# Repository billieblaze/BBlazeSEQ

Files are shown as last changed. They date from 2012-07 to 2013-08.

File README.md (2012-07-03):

BBlaze-SEQ
==========

Arduino Based Midi Sequencer w/ LCD, Nav Buttons, RGB LED Matrix / Keypad

This is my first Arduino Project, but not my first microcontroller project.   

Platform: 
=========

* SainSmart Arduino Mega 2560 clone
* SainSmart i2c LCD
* MIDI IN / MIDI OUT (6n139)
* MicroChip 24LC256 - 256k RAM 
* SparkFun 4x4 RGB LED / Button Matrix - 74hc595 shift registers for LED - 74hc164/165 for button matrix

* Navigation 
    - using a digital in module from Midibox.org - but again, just some 74hc595
    * 8 rotary encoder / swithces 
    * 5 nav buttons
    * pattern change rotary/encoder

Libraries:
==========

* SainSmart i2c LCD
* ShiftMatrixPWM
* MIDI 
* Timer3 

Roadmap: 
========

* add save / clear / copy pattern
* allow CC data in the pattern
* PCB Design

ChangeLog:
==========

* v0.9 - Split core .ino file into packages (lcd, keypad, matrix, etc) - working on timing (might remove interrupt) and general cleanup of UI handlers
* v0.8 - Added 24LC256 - working on timing of UI routines - added "record+keyboard" mode
* v0.7 - moved the button handling to an interrupt and added "updateLCD" flag which will update on the next loop()
* v0.6 - switch to i2c LCD and arduino mega 2560
* v0.5 - Replace sequence array that come from Cahors / buttons now toggle notes in the array
* v0.4 - Integrate Keypad w/ a Voltage Divider to A5
* v0.3 - Integrate LED Matrix (shiftPWMMatrix + 75hc595)
* v0.2 - LCD / Menu / Nav Buttons / Simple OS   (sainSmart LCD / Keypad)
* v0.1 - basic poc / find libraries

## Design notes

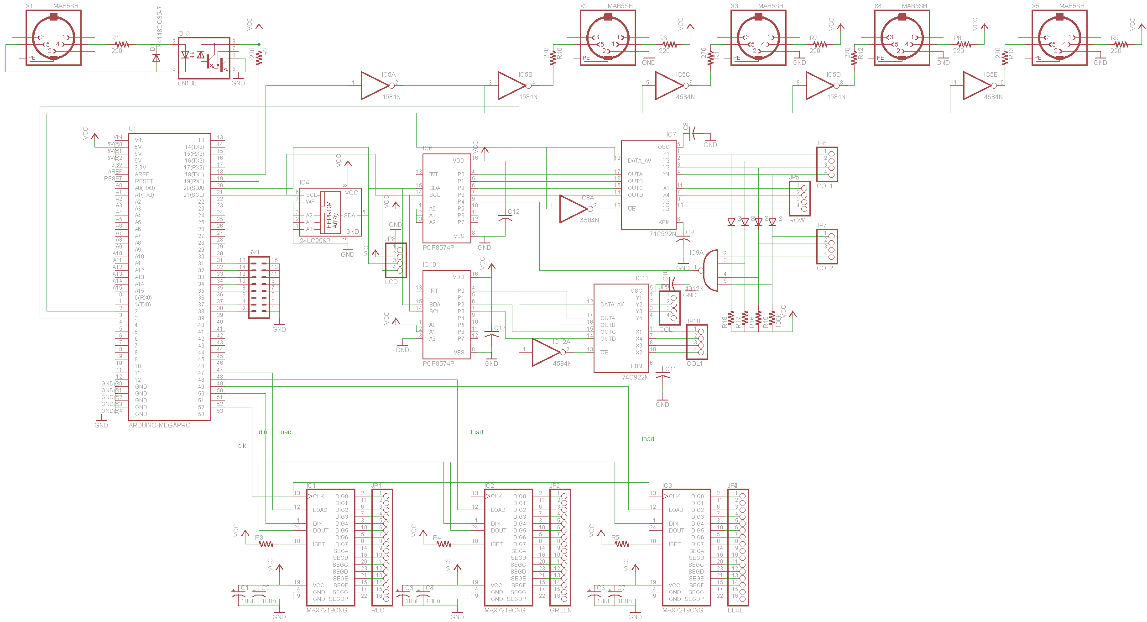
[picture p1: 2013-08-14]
bblazeSeq/schematic.png

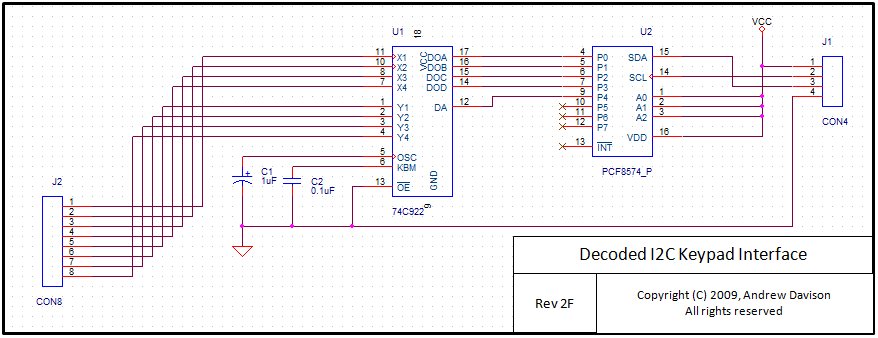
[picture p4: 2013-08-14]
bblazeSeq/74C922_circuit.png

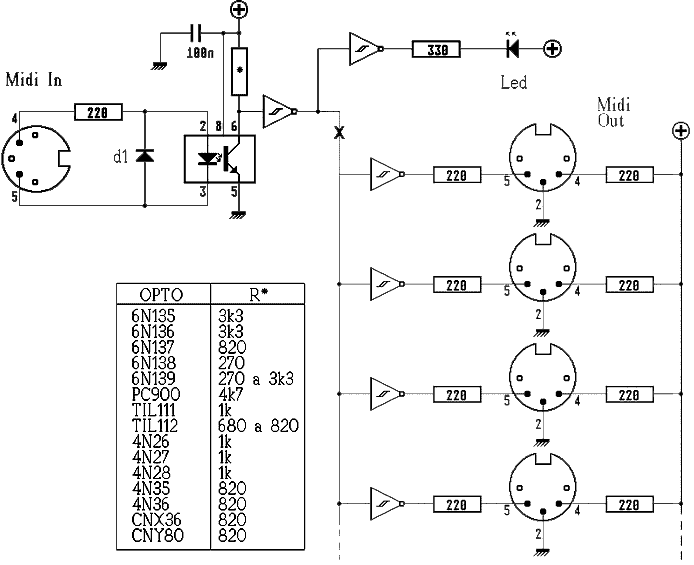
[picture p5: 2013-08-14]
bblazeSeq/midithrubox.gif

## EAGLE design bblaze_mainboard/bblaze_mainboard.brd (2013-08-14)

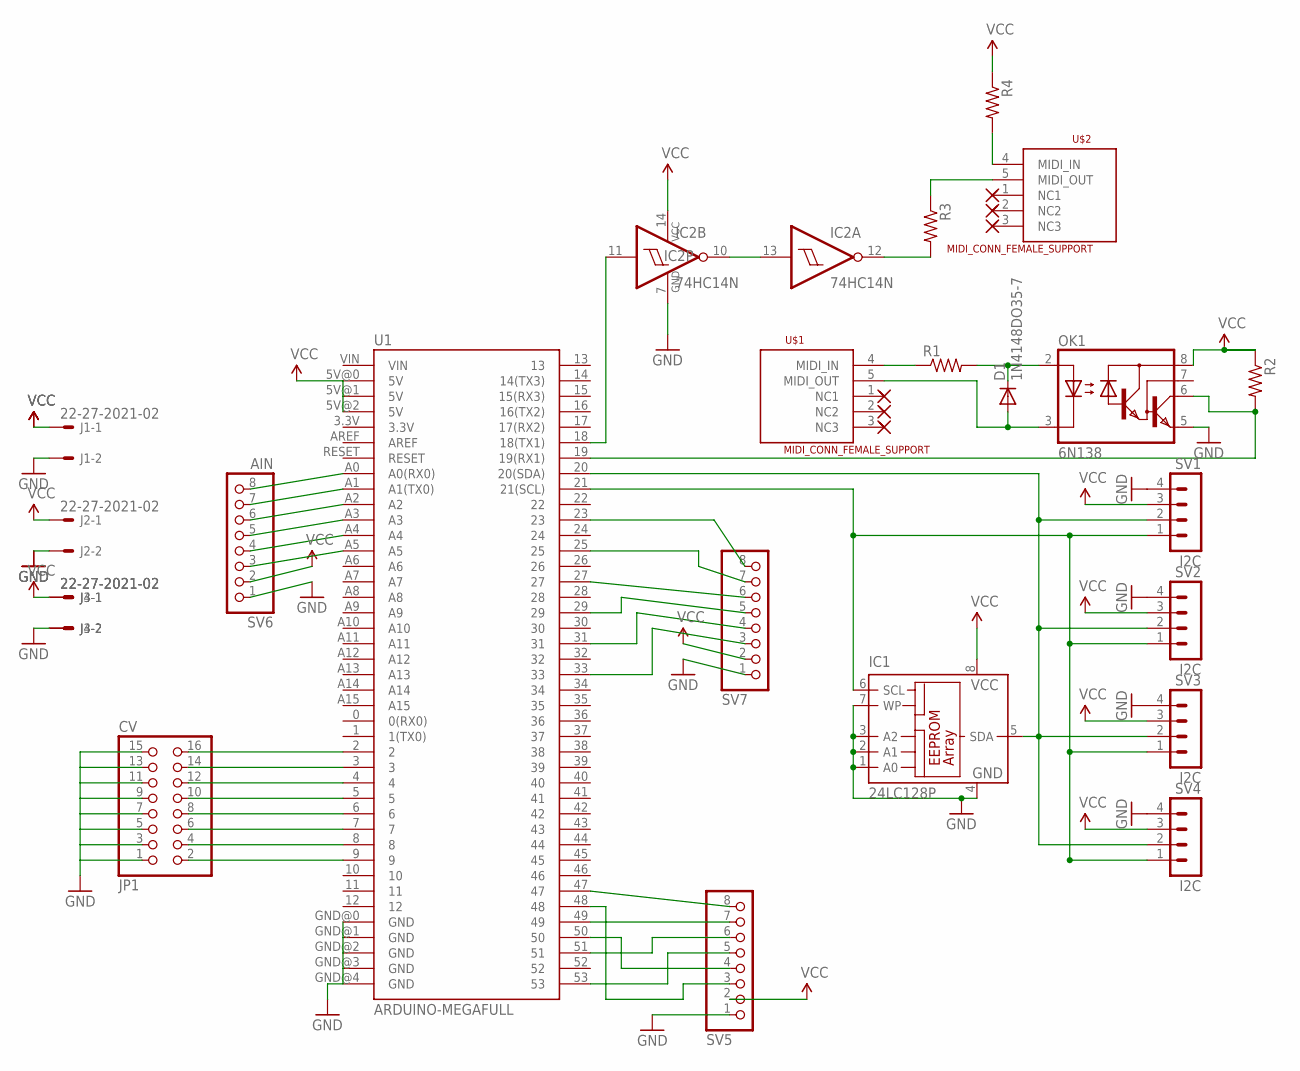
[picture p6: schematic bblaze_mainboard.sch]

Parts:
D1: 1N4148DO35-7; DO35-7
IC1: 24LC128P; DIL8
IC2: 74HC14N; DIL14
J1, J2, J3, J4: 22-27-2021-02; 6410-02
JP1: CV; 2X08
OK1: 6N138; DIL08
R1, R2, R3, R4: RESISTORKIT; AXIAL-0.3-KIT
SV1, SV2, SV3, SV4: I2C; MA04-1
SV5, SV7: PINHD-1X8; 1X08
SV6: AIN; 1X08
U1: ARDUINO-MEGAFULL; ARDUINO_MEGA
U$1, U$2: MIDI_CONN_FEMALE_SUPPORT; DIN_5_FEMALE_SUPPORT

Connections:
GND: IC1.1 (A0), IC1.2 (A1), IC1.3 (A2), IC1.4 (GND), IC1.7 (WP), IC2.7 (GND), J1.2, J2.2, J3.2, J4.2, JP1.1, JP1.3, JP1.5, JP1.7, JP1.9, JP1.11, JP1.13, JP1.15, OK1.5 (GND), SV1.4, SV2.4, SV3.4, SV4.4, SV5.1, SV6.1, SV7.1, U1.GND@0 (GND), U1.GND@1 (GND), U1.GND@2 (GND), U1.GND@3 (GND), U1.GND@4 (GND)
unnamed: D1.C, OK1.2 (A), R1.P$2 (2)
unnamed: D1.A, OK1.3 (C), U$1.5 (MIDI_OUT)
unnamed: R1.P$1 (1), U$1.4 (MIDI_IN)
unnamed: JP1.16, U1.2
unnamed: OK1.8 (VCC), R2.P$1 (1)
unnamed: OK1.6 (VO), R2.P$2 (2), U1.19 (19(RX1))
unnamed: JP1.14, U1.3
unnamed: IC1.5 (SDA), SV1.2, SV2.2, SV3.2, SV4.2, U1.20 (20(SDA))
unnamed: IC1.6 (SCL), SV1.1, SV2.1, SV3.1, SV4.1, U1.21 (21(SCL))
unnamed: JP1.12, U1.4
unnamed: JP1.10, U1.5
unnamed: JP1.8, U1.6
unnamed: JP1.6, U1.7
unnamed: JP1.4, U1.8
unnamed: JP1.2, U1.9
unnamed: SV5.5, U1.53
unnamed: SV5.6, U1.51
unnamed: SV5.4, U1.50
unnamed: SV5.3, U1.48
unnamed: SV5.8, U1.47
unnamed: IC2.11 (I), U1.18 (18(TX1))
unnamed: IC2.10 (O), IC2.13 (I)
unnamed: IC2.12 (O), R3.P$2 (2)
unnamed: R3.P$1 (1), U$2.5 (MIDI_OUT)
unnamed: R4.P$2 (2), U$2.4 (MIDI_IN)
unnamed: SV6.8, U1.A0 (A0(RX0))
unnamed: SV6.7, U1.A1 (A1(TX0))
unnamed: SV6.6, U1.A2
unnamed: SV6.5, U1.A3
unnamed: SV6.4, U1.A4
unnamed: SV6.3, U1.A5
unnamed: SV7.8, U1.23
unnamed: SV7.7, U1.25
unnamed: SV7.6, U1.27
unnamed: SV7.5, U1.29
unnamed: SV7.4, U1.31
unnamed: SV7.3, U1.33
unnamed: SV5.7, U1.49
VCC: IC1.8 (VCC), IC2.14 (VCC), J1.1, J2.1, J3.1, J4.1, R4.P$1 (1), SV1.3, SV2.3, SV3.3, SV4.3, SV5.2, SV6.2, SV7.2, U1.5V@0 (5V), U1.5V@1 (5V), U1.5V@2 (5V)

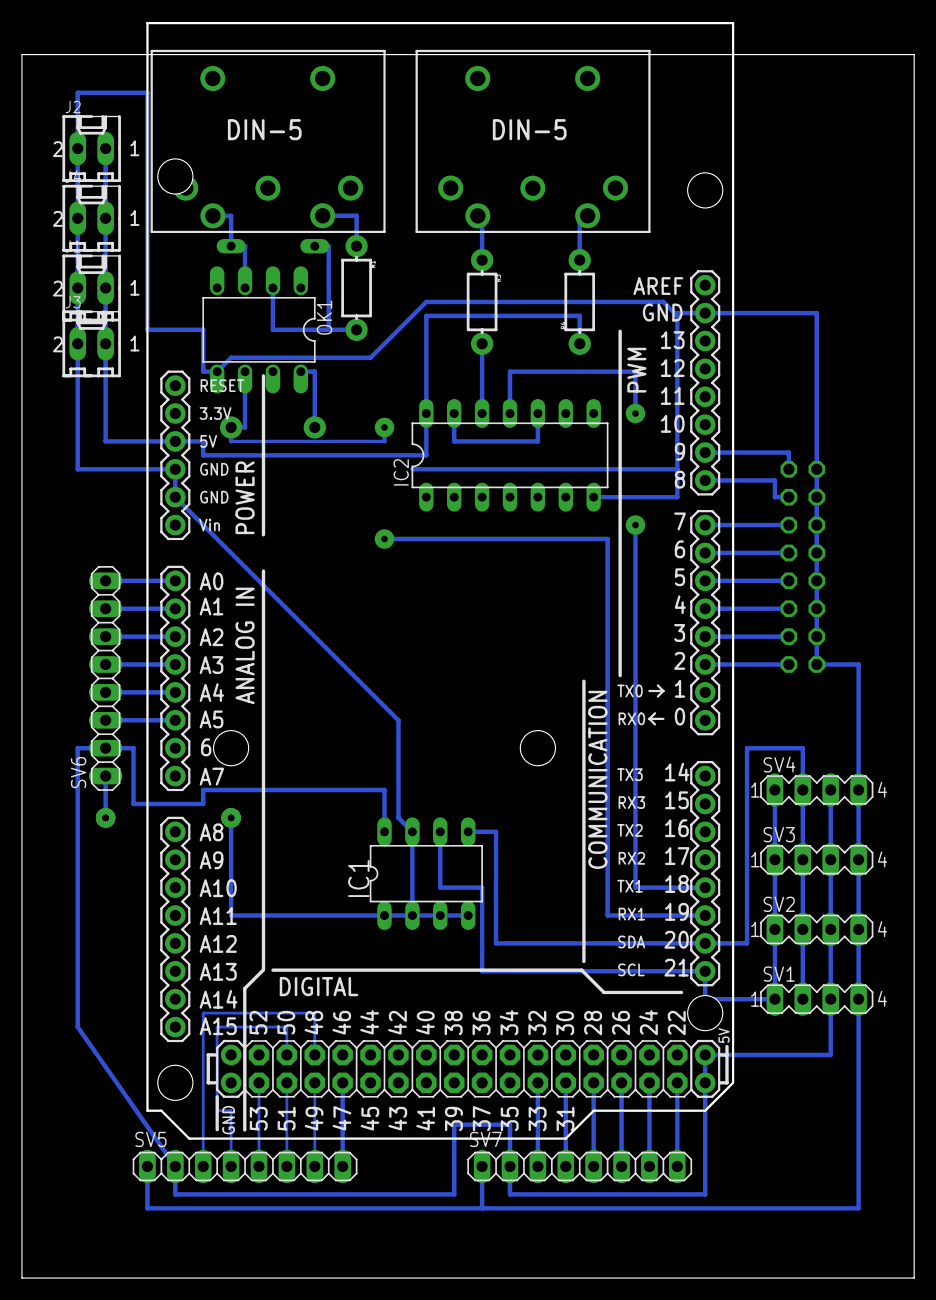
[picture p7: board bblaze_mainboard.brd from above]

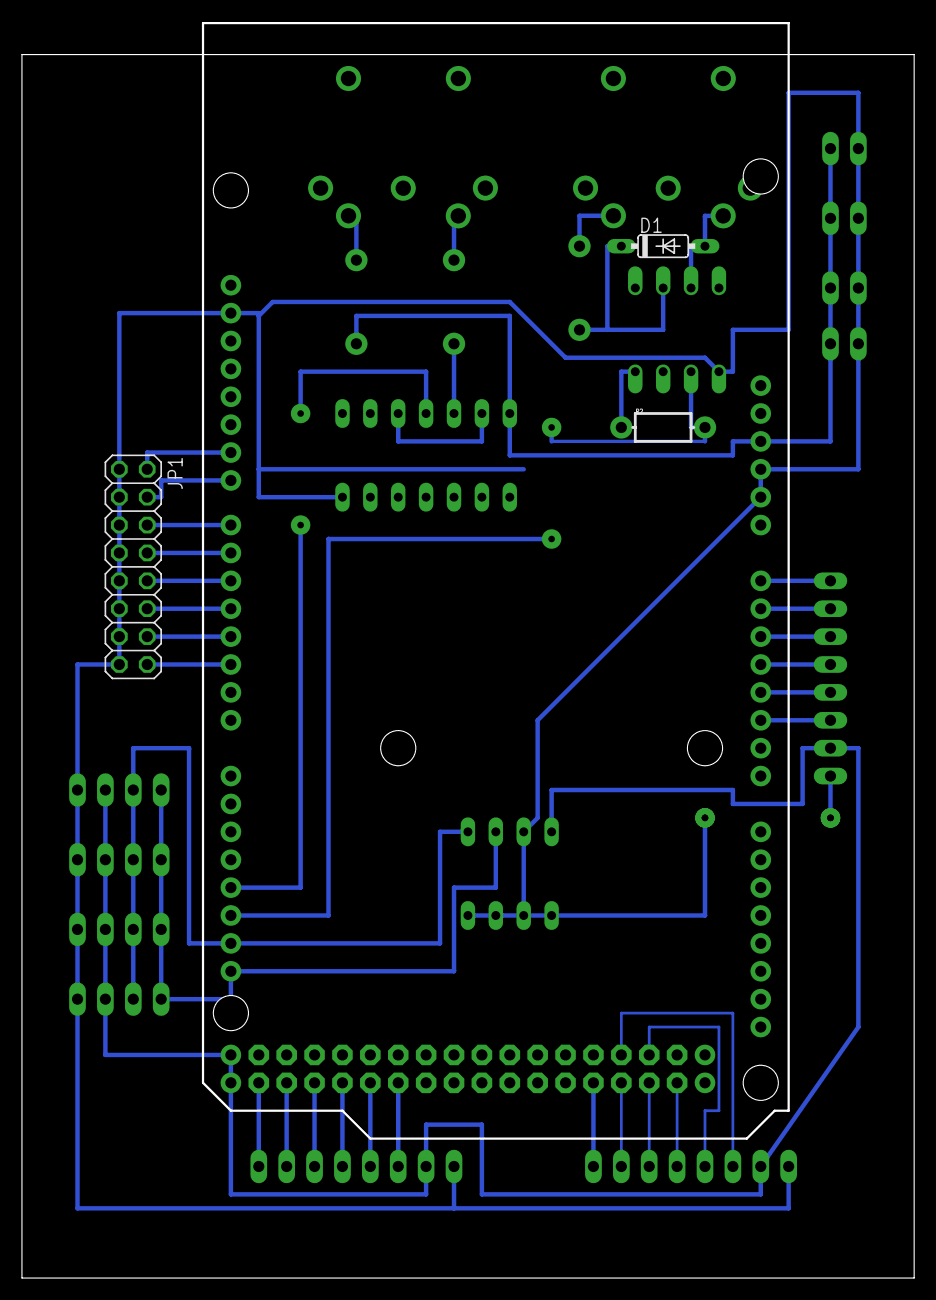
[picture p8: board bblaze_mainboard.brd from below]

Board: 2 copper layers, 81.3 x 114.3 mm, 23 parts (3 on the bottom side), 40 nets.

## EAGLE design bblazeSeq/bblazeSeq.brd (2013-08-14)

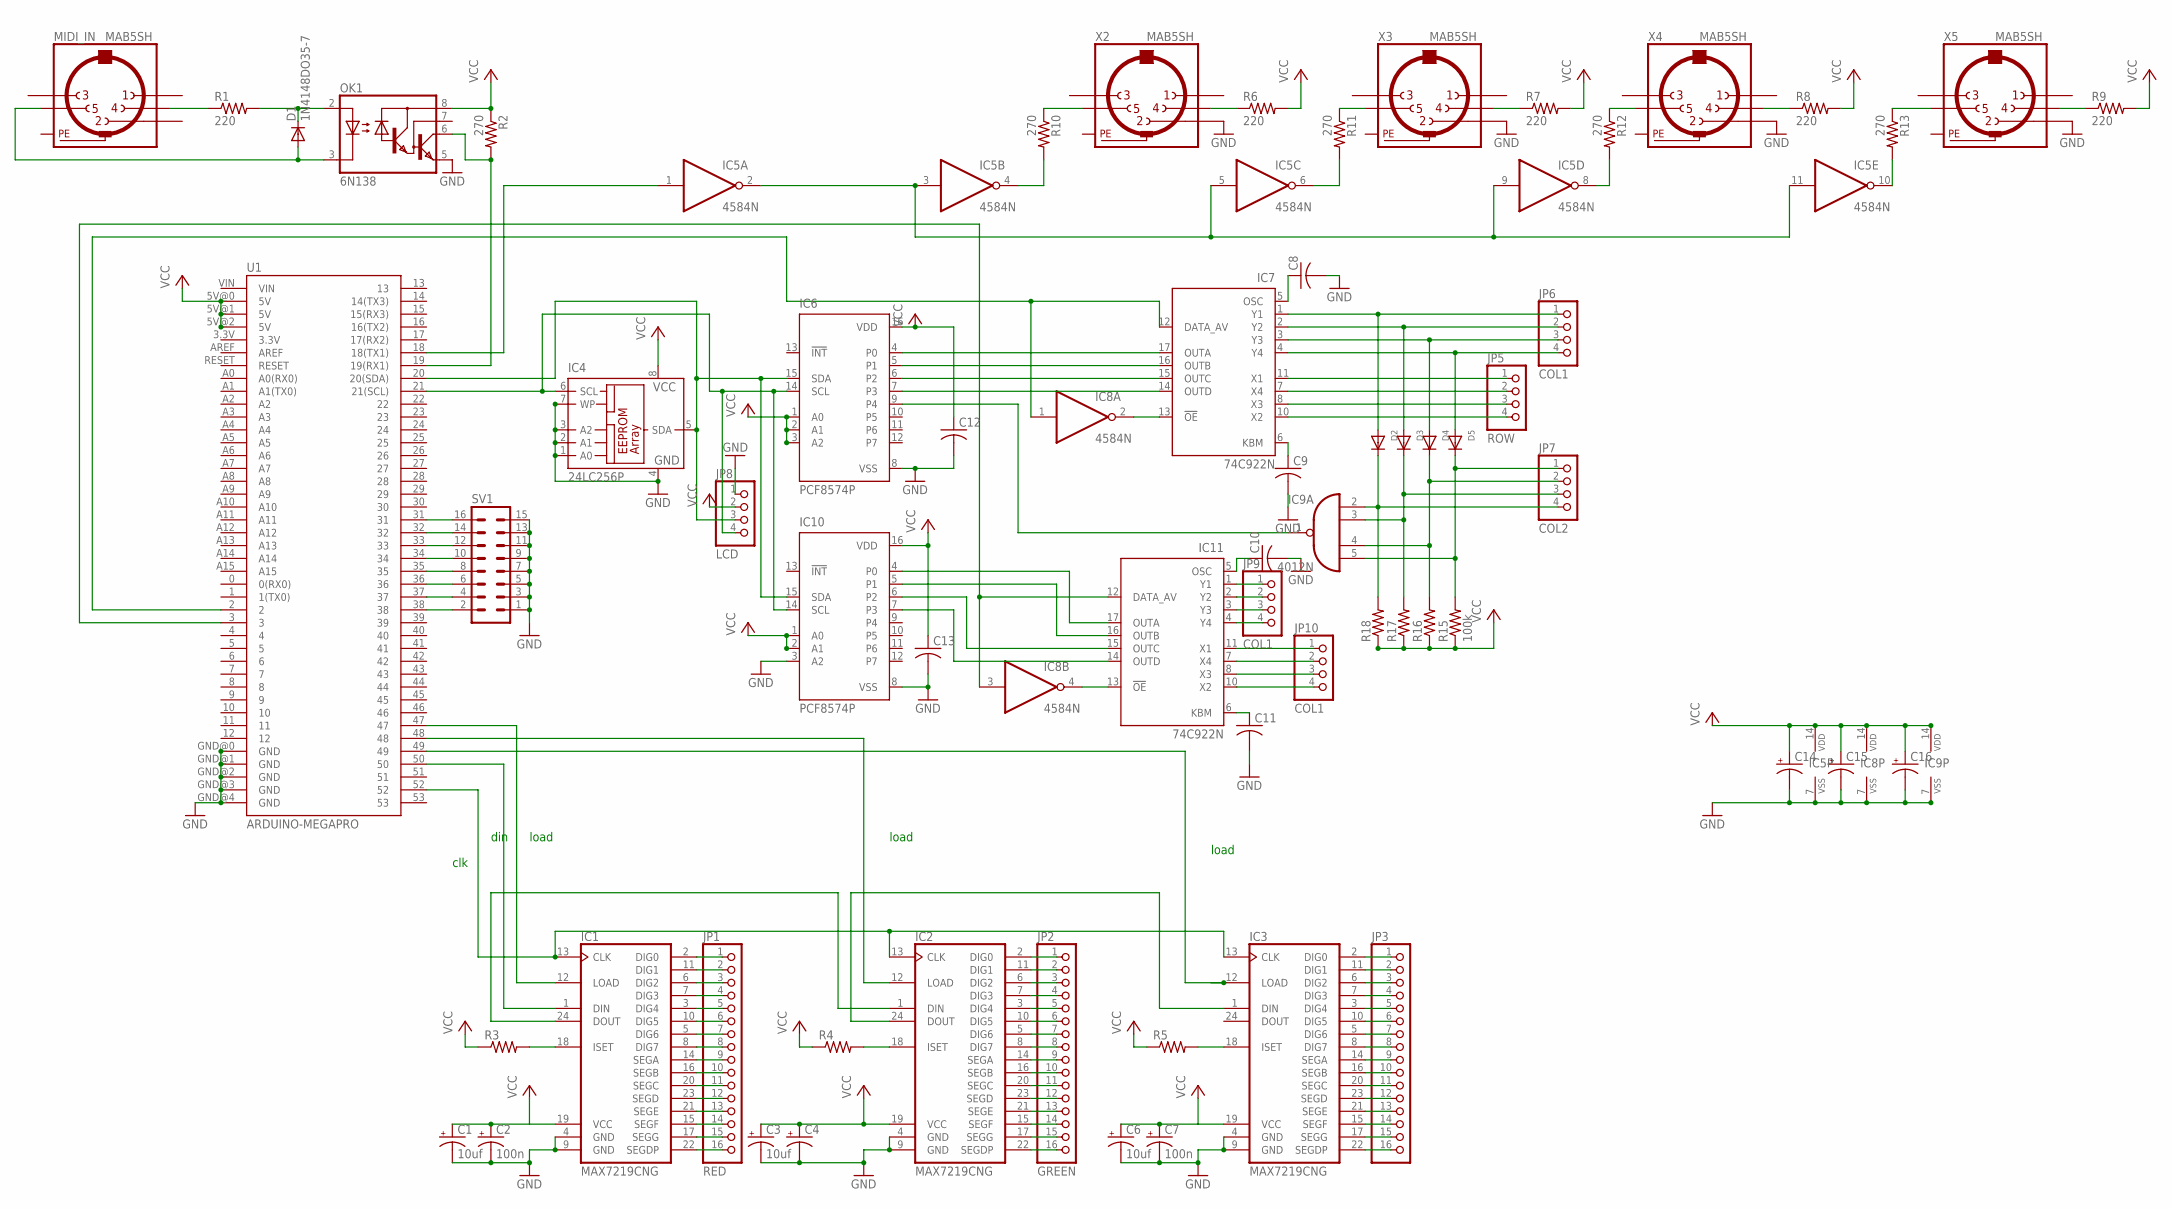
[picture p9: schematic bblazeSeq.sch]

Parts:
C1, C3, C6: 10uf; E2,5-6E
C2, C7: 100n; E2,5-6E
C4, C14, C15, C16: CPOL-USE2,5-6E; E2,5-6E
C8, C9, C10, C11, C12, C13: C-US050-024X044; C050-024X044
D1: 1N4148DO35-7; DO35-7
D2, D3, D4, D5: DIODEDO-1N4148; DO-1N4148
IC1, IC2, IC3: MAX7219CNG; DIL24-3
IC4: 24LC256P; DIL8
IC5, IC8: 4584N; DIL14
IC6, IC10: PCF8574P; DIL16
IC7, IC11: 74C922N; DIL18
IC9: 4012N; DIL14
JP1: RED; 1X16
JP2: GREEN; 1X16
JP3: PINHD-1X16; 1X16
JP5: ROW; 1X04
JP6, JP9, JP10: COL1; 1X04
JP7: COL2; 1X04
JP8: LCD; 1X04
MIDI_IN: MAB5SH
OK1: 6N138; DIL08
R1: 220; 0207/10
R2, R10, R11, R12, R13: 270; 0207/10
R3, R4, R5, R16, R17, R18: R-US_0204/7; 0204/7
R6, R7, R8, R9: 220; 0204/7
R15: 100k; 0204/7
SV1: MA08-2
U1: ARDUINO-MEGAPRO; ARDUINO_MEGA-PRO-3.3V
X2, X3, X4, X5: MAB5SH

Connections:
GND: C1.-, C2.-, C3.-, C4.-, C6.-, C7.-, C8.2, C9.2, C10.2, C11.2, C12.2, C13.2, C14.-, C15.-, C16.-, IC1.4 (GND), IC1.9 (GND), IC2.4 (GND), IC2.9 (GND), IC3.4 (GND), IC3.9 (GND), IC4.1 (A0), IC4.2 (A1), IC4.3 (A2), IC4.4 (GND), IC4.7 (WP), IC5.7 (VSS), IC6.8 (VSS), IC7.9 (GND), IC8.7 (VSS), IC9.7 (VSS), IC10.3 (A2), IC10.8 (VSS), IC11.9 (GND), JP8.1, OK1.5 (GND), SV1.1, SV1.3, SV1.5, SV1.7, SV1.9, SV1.11, SV1.13, SV1.15, U1.GND@0 (GND), U1.GND@1 (GND), U1.GND@2 (GND), U1.GND@3 (GND), U1.GND@4 (GND), X2.2, X3.2, X4.2, X5.2
unnamed: IC6.9 (P4), IC9.1 (O)
unnamed: D2.C, IC9.2 (I0), JP7.4, R18.2
unnamed: D3.C, IC9.3 (I1), JP7.3, R17.2
unnamed: D4.C, IC9.4 (I2), JP7.2, R16.2
unnamed: D5.C, IC9.5 (I3), JP7.1, R15.2
unnamed: IC3.2 (DIG0), JP3.1
unnamed: IC3.11 (DIG1), JP3.2
unnamed: IC3.6 (DIG2), JP3.3
unnamed: IC3.7 (DIG3), JP3.4
unnamed: IC3.3 (DIG4), JP3.5
unnamed: IC3.10 (DIG5), JP3.6
unnamed: IC3.5 (DIG6), JP3.7
unnamed: IC3.8 (DIG7), JP3.8
unnamed: IC3.14 (SEGA), JP3.9
unnamed: D1.A, MIDI_IN.5, OK1.3 (C)
unnamed: D1.C, OK1.2 (A), R1.2
unnamed: MIDI_IN.4, R1.1
unnamed: OK1.6 (VO), R2.2, U1.19 (19(RX1))
unnamed: IC1.18 (ISET), R3.2
unnamed: IC4.6 (SCL), IC6.14 (SCL), IC10.14 (SCL), JP8.4, U1.21 (21(SCL))
unnamed: IC4.5 (SDA), IC6.15 (SDA), IC10.15 (SDA), JP8.3, U1.20 (20(SDA))
unnamed: IC2.18 (ISET), R4.2
unnamed: IC3.18 (ISET), R5.2
unnamed: IC3.12 (LOAD), U1.49
unnamed: IC2.12 (LOAD), U1.48
unnamed: C1.+, C2.+, IC1.19 (VCC)
unnamed: IC5.1 (I), U1.18 (18(TX1))
unnamed: C6.+, C7.+, IC3.19 (VCC)
unnamed: IC2.24 (DOUT), IC3.1 (DIN)
unnamed: IC1.24 (DOUT), IC2.1 (DIN)
unnamed: IC1.13 (CLK), IC2.13 (CLK), IC3.13 (CLK), U1.52
unnamed: R6.1, X2.4
unnamed: IC1.1 (DIN), U1.50
unnamed: IC1.12 (LOAD), U1.47
unnamed: R7.1, X3.4
unnamed: R8.1, X4.4
unnamed: R9.1, X5.4
unnamed: R10.1, X2.5
unnamed: R11.1, X3.5
unnamed: R12.1, X4.5
unnamed: R13.1, X5.5
unnamed: IC5.4 (O), R10.2
unnamed: IC5.6 (O), R11.2
unnamed: IC5.8 (O), R12.2
unnamed: IC5.10 (O), R13.2
unnamed: IC5.2 (O), IC5.3 (I), IC5.5 (I), IC5.9 (I), IC5.11 (I)
unnamed: IC7.12 (DATA_AV), IC8.1 (I), U1.2
unnamed: IC6.4 (P0), IC7.17 (OUTA)
unnamed: IC6.5 (P1), IC7.16 (OUTB)
unnamed: IC6.6 (P2), IC7.15 (OUTC)
unnamed: IC6.7 (P3), IC7.14 (OUTD)
unnamed: C9.1, IC7.6 (KBM)
unnamed: C8.1, IC7.5 (OSC)
unnamed: IC7.13 (!OE), IC8.2 (O)
unnamed: IC7.11 (X1), JP5.1
unnamed: IC7.7 (X4), JP5.2
unnamed: IC7.8 (X3), JP5.3
unnamed: IC7.10 (X2), JP5.4
unnamed: D2.A, IC7.1 (Y1), JP6.1
unnamed: D3.A, IC7.2 (Y2), JP6.2
unnamed: D4.A, IC7.3 (Y3), JP6.3
unnamed: D5.A, IC7.4 (Y4), JP6.4
unnamed: IC3.16 (SEGB), JP3.10
unnamed: IC3.20 (SEGC), JP3.11
unnamed: IC3.23 (SEGD), JP3.12
unnamed: IC3.21 (SEGE), JP3.13
unnamed: IC3.15 (SEGF), JP3.14
unnamed: IC3.17 (SEGG), JP3.15
unnamed: IC3.22 (SEGDP), JP3.16
unnamed: IC1.2 (DIG0), JP1.1
unnamed: IC1.11 (DIG1), JP1.2
unnamed: IC1.6 (DIG2), JP1.3
unnamed: IC1.7 (DIG3), JP1.4
unnamed: IC1.3 (DIG4), JP1.5
unnamed: IC1.10 (DIG5), JP1.6
unnamed: IC1.5 (DIG6), JP1.7
unnamed: IC1.8 (DIG7), JP1.8
unnamed: IC1.14 (SEGA), JP1.9
unnamed: IC1.16 (SEGB), JP1.10
unnamed: IC1.20 (SEGC), JP1.11
unnamed: IC1.23 (SEGD), JP1.12
unnamed: IC1.21 (SEGE), JP1.13
unnamed: IC1.15 (SEGF), JP1.14
unnamed: IC1.17 (SEGG), JP1.15
unnamed: IC1.22 (SEGDP), JP1.16
unnamed: IC2.2 (DIG0), JP2.1
unnamed: IC2.11 (DIG1), JP2.2
unnamed: IC2.6 (DIG2), JP2.3
unnamed: IC2.7 (DIG3), JP2.4
unnamed: IC2.3 (DIG4), JP2.5
unnamed: IC2.10 (DIG5), JP2.6
unnamed: IC2.5 (DIG6), JP2.7
unnamed: IC2.8 (DIG7), JP2.8
unnamed: IC2.14 (SEGA), JP2.9
unnamed: IC2.16 (SEGB), JP2.10
unnamed: IC2.20 (SEGC), JP2.11
unnamed: IC2.23 (SEGD), JP2.12
unnamed: IC2.21 (SEGE), JP2.13
unnamed: IC2.15 (SEGF), JP2.14
unnamed: IC2.17 (SEGG), JP2.15
unnamed: IC2.22 (SEGDP), JP2.16
unnamed: IC8.4 (O), IC11.13 (!OE)
unnamed: IC8.3 (I), IC11.12 (DATA_AV), U1.3
unnamed: IC10.4 (P0), IC11.17 (OUTA)
unnamed: IC10.5 (P1), IC11.16 (OUTB)
unnamed: IC10.6 (P2), IC11.15 (OUTC)
unnamed: IC10.7 (P3), IC11.14 (OUTD)
unnamed: C10.1, IC11.5 (OSC)
unnamed: C11.1, IC11.6 (KBM)
unnamed: IC11.1 (Y1), JP9.1
unnamed: IC11.2 (Y2), JP9.2
unnamed: IC11.3 (Y3), JP9.3
unnamed: IC11.4 (Y4), JP9.4
unnamed: IC11.11 (X1), JP10.1
unnamed: IC11.7 (X4), JP10.2
unnamed: IC11.8 (X3), JP10.3
unnamed: IC11.10 (X2), JP10.4
unnamed: SV1.16, U1.31
unnamed: SV1.14, U1.32
unnamed: SV1.12, U1.33
unnamed: SV1.10, U1.34
unnamed: SV1.8, U1.35
unnamed: SV1.6, U1.36
unnamed: SV1.4, U1.37
unnamed: SV1.2, U1.38
PE: MIDI_IN.PE, MIDI_IN.PE@ (PE), X2.PE, X2.PE@ (PE), X3.PE, X3.PE@ (PE), X4.PE, X4.PE@ (PE), X5.PE, X5.PE@ (PE)
VCC: C3.+, C4.+, C12.1, C13.1, C14.+, C15.+, C16.+, IC2.19 (VCC), IC4.8 (VCC), IC5.14 (VDD), IC6.1 (A0), IC6.2 (A1), IC6.3 (A2), IC6.16 (VDD), IC7.18 (VCC), IC8.14 (VDD), IC9.14 (VDD), IC10.1 (A0), IC10.2 (A1), IC10.16 (VDD), IC11.18 (VCC), JP8.2, OK1.8 (VCC), R2.1, R3.1, R4.1, R5.1, R6.2, R7.2, R8.2, R9.2, R15.1, R16.1, R17.1, R18.1, U1.5V@0 (5V), U1.5V@1 (5V), U1.5V@2 (5V)

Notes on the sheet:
clk
din
load

Board: 2 copper layers, 65 parts (0 on the bottom side), 128 nets, no tracks yet.

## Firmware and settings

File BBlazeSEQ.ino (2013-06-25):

/*BBlazeSeq v0.8 */

// TODO: redo bottom button column connector! 
// TODO: create / save(pattern knob button) multiple patterns - calculate out the storage requirements for such data and how many patterns i could hold 
// TODO: allow CC data in the pattern - maybe just filter initially? 
// todo: check rotary 3 and 9

#include "constants.h"
#include <stdio.h>
#include <stdlib.h>

#include <Wire.h>

#include "SPI.h"

#include <MIDI.h>
#include <LiquidCrystal_I2C.h>
#include <digitalWriteFast.h>

#include "config.h"  
#include <ShiftMatrixPWM.h> // included last because pins are declared in config.h



#include "midi.h"

#include "keypad.h"
#include "navkeys.h"
#include "encoders.h"
#include "UI.h"


#include "matrix.h"
#include "lcd.h"


// Setup
void setup(){
  //Serial.begin(9600);
  setupLCD();
  setupLEDMatrix(); 
  setupKeypad();
  setupMIDI();
 }

// Main Loop
void loop(){
 startTime = millis();
 MIDI.read();
 scanUI();
 handleMatrix();
 handleEncoders(); 
 handleNavButtons(); 
 handleKeypad();
 updateLCDArray();
 writeToLCD(); 
}

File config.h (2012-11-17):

String version = "0.9";
 unsigned long LCDLastUpdated=0;
// LCD - using a sainSmart i2c LCD connected to 20/21 of my MEGA
  LiquidCrystal_I2C lcd(0x27,20,4);  // set the LCD address to 0x27 for a 16 chars and 2 line display
  
// ShiftMatrixPWM handles the led matrix and connects to a group of 3 daisy chained 74hc595's to control RGB (columns) and a seperate 74hc595 (rows)
  //Data pin is MOSI (atmega168/328: pin 11. Mega: 51) 
  //Clock pin is SCK (atmega168/328: pin 13. Mega: 52)
    const int ShiftMatrixPWM_columnLatchPin=49;
    const int ShiftMatrixPWM_rowDataPin=A15;
    const int ShiftMatrixPWM_rowClockPin=A14;
    const int ShiftMatrixPWM_rowLatchPin=A13;
    
    const bool ShiftMatrixPWM_invertColumnOutputs = 0; // if invertColumnOutputs is 1, outputs will be active low. Usefull for common anode RGB led's.
    const bool ShiftMatrixPWM_invertRowOutputs = 1; // if invertOutputs is 1, outputs will be active low. Used for PNP transistors.
    
    unsigned char maxBrightness = 10;
    unsigned char pwmFrequency = 60;
    
    int numColumnRegisters = 3; 
    int numRows=4;
    
    int numColumns = numColumnRegisters*8;
    int numOutputs = numColumns*numRows;
    
    int lastRow = 0;
    int lastCol = 0;

    // button -> tick mapping
    boolean buttonMapping[4][8] = 
    {
      {31,30,29,28,27,24,25,26},
      {7,6,5,4,3,0,1,2},
      {15,14,13,12,11,8,9,10},
      {23,22,21,20,19,16,17,18},

    };



// The key matrix connect to 74hc164 / 165 to shift in / out keys 
    const int keypadOutputClockPin=A9;
    const int keypadOutputDataPin=A8;
    
    // shiftout
    int ploadPin        = A11;  // Connects to Parallel load pin the 165
    int dataPin         = A10; // Connects to the Q7 pin the 165
    int clockPin        = A12; // Connects to the Clock pin the 165
    


// navigation keys 
    int navploadPin        = 26;  // Connects to Parallel load pin the 165
    int navdataPin         = 22; // Connects to the Q7 pin the 165
    int navclockPin        = 24; // Connects to the Clock pin the 165

  
    int encoderMapping[9][3] = {
    // byte array row, then the actual bit (0,1) number position for that encoder
      {0,2,3}, // ENC 1
      {1,4,5}, // ENC 2
      {2,7,6}, // ENC 3
      {2,2,3}, // ENC 4
      {0,5,6}, // ENC 5
      {0,0,1}, // ENC 6
      {1,1,2}, // ENC 7
      {2,3,4}, // ENC 8
      {3,1,2}, // ENC 9  - pattern knob
    };
    
    int encoderButtonMapping[9] = {
      0, // ENC_B 1
      9, // ENC_B 2
      15, // ENC_B 3
      23, // ENC_B 4
      8, // ENC_B 5
      0, // ENC_B 6
      12, // ENC_B 7
      20, // ENC_B 8
      31  // ENC_B 9
    };
    
    int navButtonMapping[8] = {
      27, // up
      25, // down
      28, // left
      26, // right
      25, // center
    };

// Clock and Counter - all the bits the sequencer uses to track position / time / etc
    int channels = 15;
          int updateMatrix = 1;
        int updateLCD = 1;
        
          byte oldNavKeyValues[]={255,255,255,255};
    byte newNavKeyValues[]={255,255,255,255};


   
    unsigned long UILastUpdated=0;
    unsigned long startTime = 0;
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

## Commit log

2012-05-02 lol, arduino wouldn't take a - in the sketch name!
2012-05-03 fixes to nav keypad after introducing shiftMatrixPWM LED Matrix scanning is synced to the main loop now..
2012-05-06 stripped back song format - used voltage divider and analog pin to POC the keypad integration
2012-05-08 adjusted timing / note + velocity arrays..
2012-05-16 split up config - added keypad decoder - added another button pad
2012-07-03 fix keypad polling issues after refactoring the interrupt / service routine
    [BBlazeSEQ.ino, keypad.h]
2012-07-05 Added test sketches which have been used to verify different stages of the hardware design
2012-07-26 worked on rotary encoders quite a bit - still a little flaky, but getting better
2012-08-10 fixes to keypad scanning..
    was not shifting in right and was missing 2 bits.. maybe ditch the
    shiftOuts since i'm on Mega now?
    [config.h, keypad.h, keypadtest.ino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]
2012-09-11 fixed glitch in keypad
    [BBlazeSEQ.ino, keypad.h]
2012-09-25 added more midi.read to prevent timing glitches and found a misplaced updateMatrix which was causing matrix refresh every loop
    [BBlazeSEQ.ino, MIDI_Input.ino, config.h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]
2013-08-14 add initial eagle files
    [bblazeSeq.brd, bblazeSeq.sch, bblaze_mainboard.brd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]

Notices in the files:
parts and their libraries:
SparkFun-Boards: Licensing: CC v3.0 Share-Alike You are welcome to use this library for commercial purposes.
